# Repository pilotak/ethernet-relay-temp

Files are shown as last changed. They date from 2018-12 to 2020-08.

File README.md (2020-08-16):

# STM32F103C8 (BluePill) based temperature node with relay



## Features
- variable power supply: 5-15V (depends on relay coil)
- 1-wire bus for DS18B20 temperature sensors
- 1x thermistor input
- 1x SPST relay with ARC suppression
- controlled over MQTT

## MQTT topics
- `nameOfBoard/dtemp/*` = dallas temperature *(aterisk is temp address)*
- `nameOfBoard/atemp/*` = thermistor temperature *(aterisk is analog temp index)*
- `nameOfBoard/status` = online status
- `nameOfBoard/err` = dallas error, tells you index of the bad sensor
- `nameOfBoard/count` = number of dallas sensors found
- `nameOfBoard/relay/0` = state of relay
- `nameOfBoard/relay/0/set` = command for relay, can be either `0` or `1`

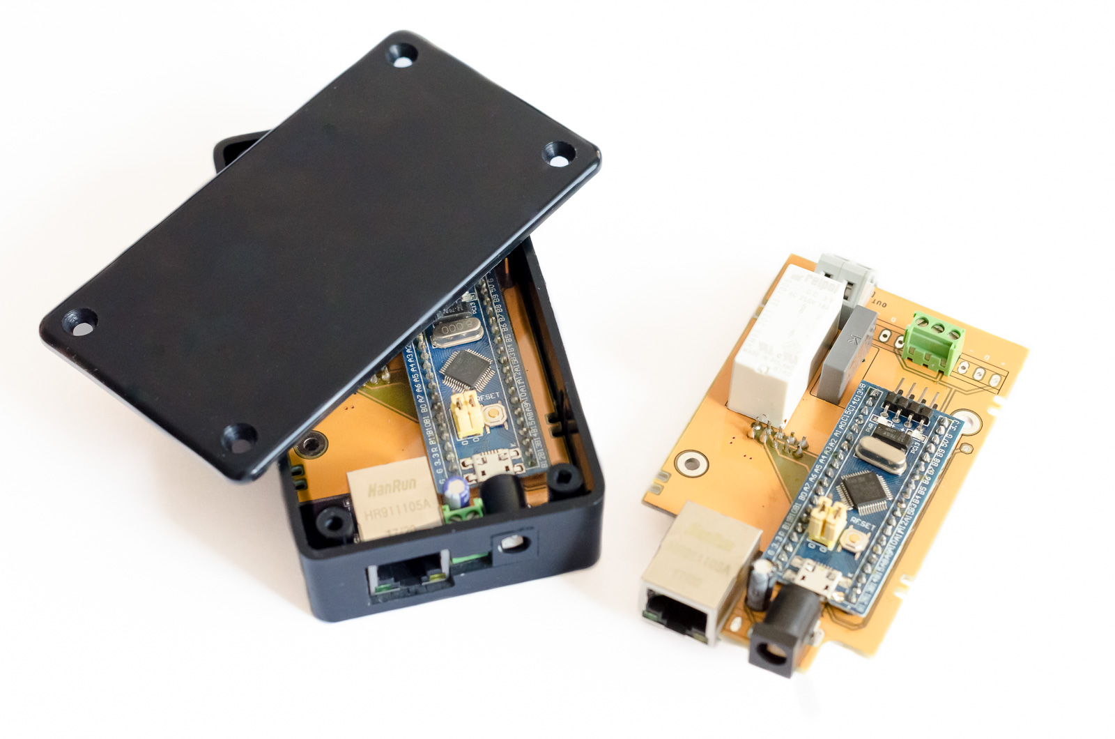
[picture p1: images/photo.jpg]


## BOM
| Qty | Component | Value | Package |
|:---:| --- | ----- | --- |
| 1 | Ceramic capacitor | 10uF | C0805 |
| 1 | Electrolytic capacitor | 100uF | E2-5 |
| 1 | Polypropylene capacitor | R463I24705001K | C150-084X183 |
| 1 | Diode | S1B |DO214AC (SMA) |
| 1 | Shottky diode | SS16 | DO214AC (SMA) |
| 1 | Barrel jack | 2.1mm | |
| 1 | Relay | RM85-2021-35-1005 | |
| 1 | NPN transistor | BC817 | SOT23-BEC |
| 1 | Resistor | 1K | R0805 |
| 1 | Resistor | 4K7 | R0805 |
| 1 | Resistor | 10K | R0805 |
| 1 | Resistor | 160R | R2010 |
| 1 | Ethernet module | ENC28J60 | |
| 1 | LDO regulator | LM1117-3.3 | SOT223 |
| 1 | Processor module | STM32F103C8T6 | |
| 2 | Terminal | Wago 236-740-5,08 | |
| 1 | Terminal | KF350-3.50-2P | |
| 3 | Terminal | KF350-3.50-3P | |
| 1 | Case | KRADEX Z76 | |

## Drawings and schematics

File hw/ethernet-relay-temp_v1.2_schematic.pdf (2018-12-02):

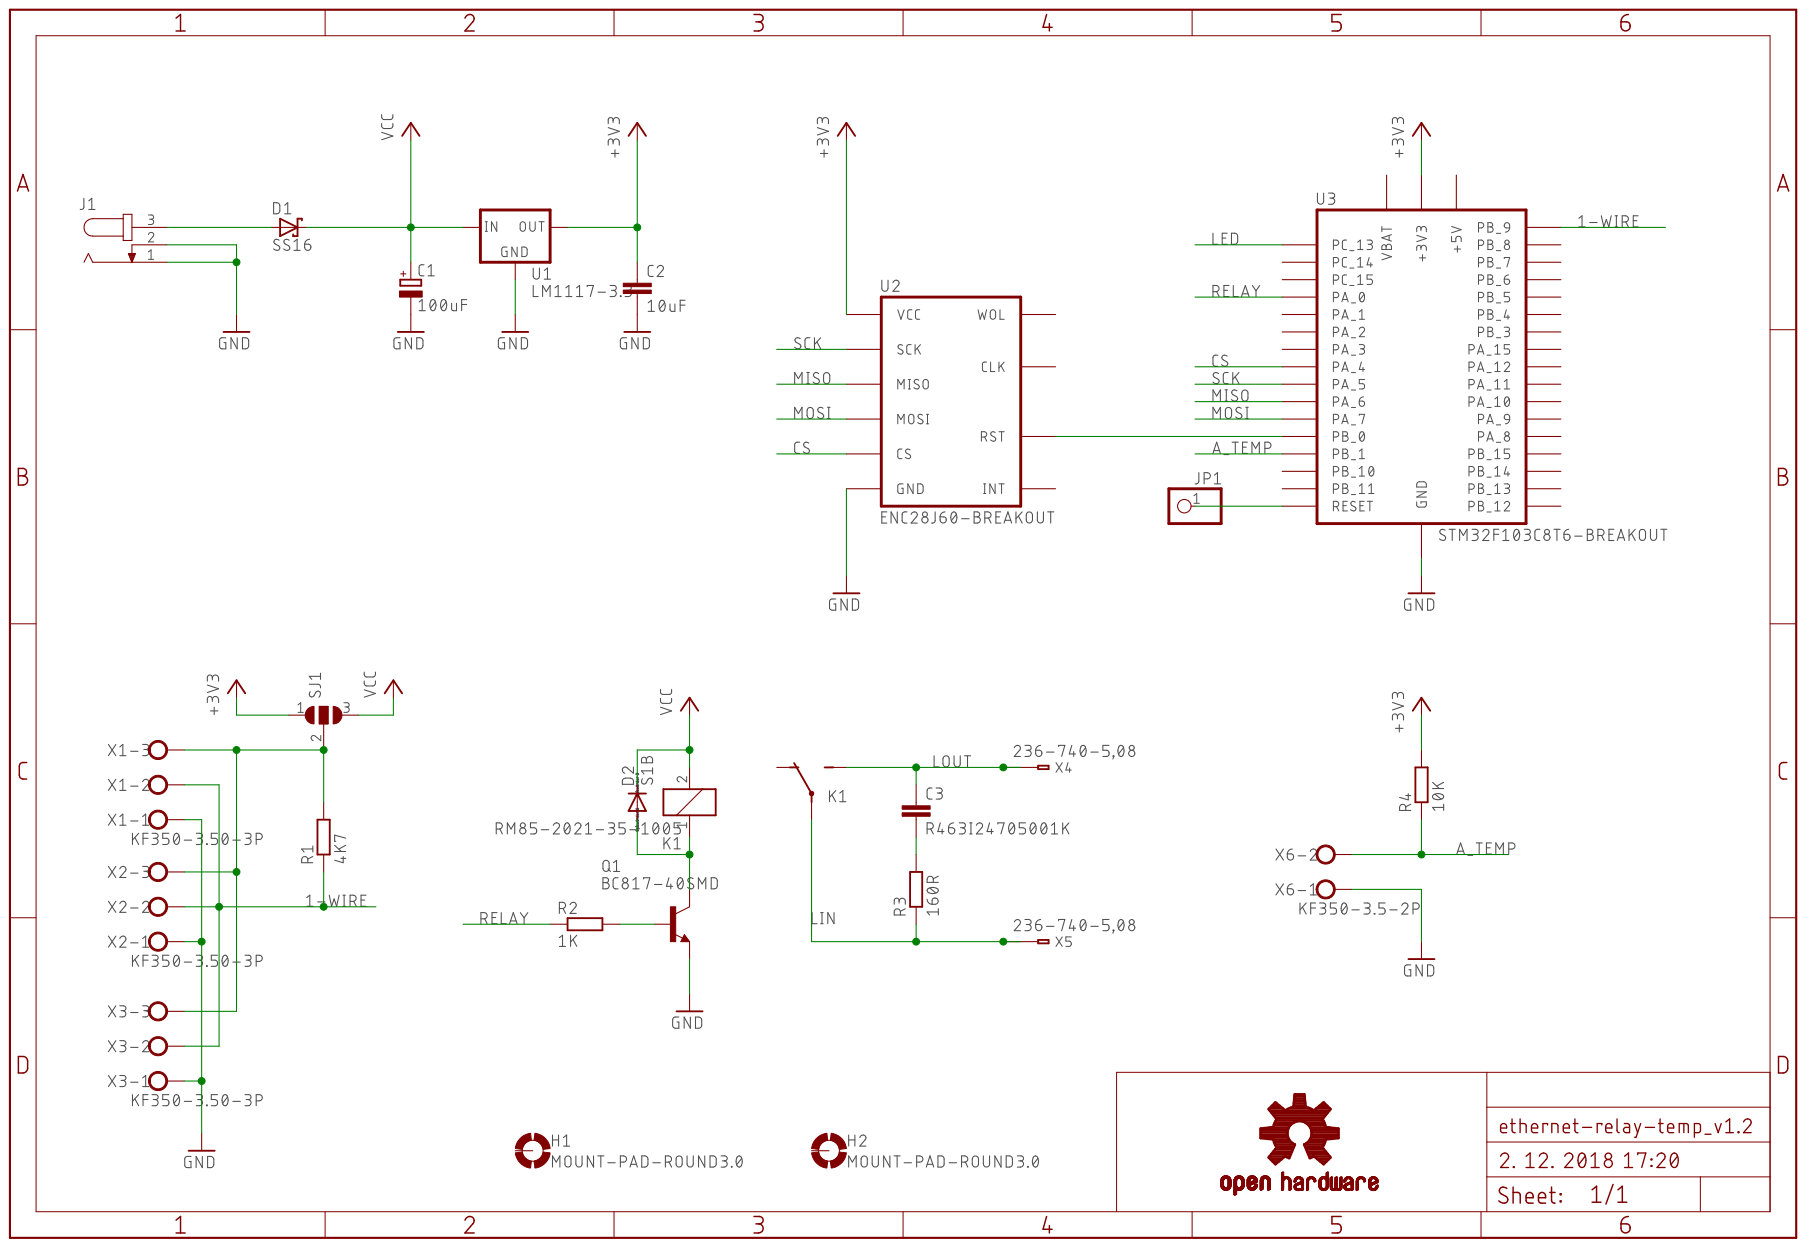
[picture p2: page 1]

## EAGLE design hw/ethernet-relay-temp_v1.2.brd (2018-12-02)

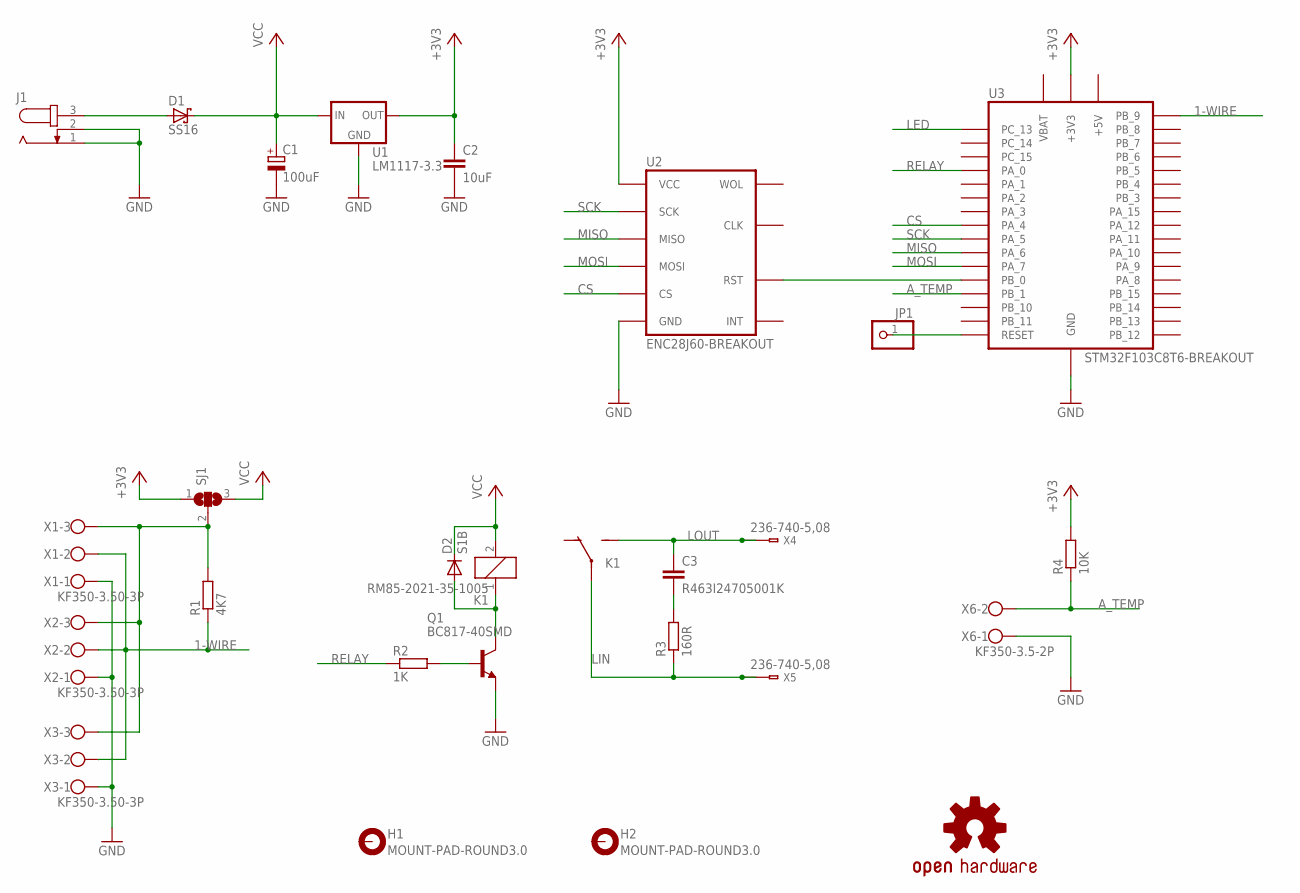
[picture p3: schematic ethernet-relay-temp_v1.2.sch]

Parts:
C1: 100uF; E2-5
C2: 10uF; C0805
C3: R463I24705001K; C150-084X183
D1: SS16; DO214AC
D2: S1B; DO214AC
H1, H2: MOUNT-PAD-ROUND3.0; 3,0-PAD
J1: JACK-PLUG0; SPC4077
JP1: PINHD-1X1; 1X01
K1: RM85-2021-35-1005; RM85
LOGO1: OSHW-LOGOS-COPPER; OSHW-LOGO-S_COPPER
Q1: BC817-40SMD; SOT23-BEC
R1: 4K7; R0805
R2: 1K; R0805
R3: 160R; R2010
R4: 10K; R0805
SJ1: SJ2W; SJ_2
U1: LM1117-3.3; SOT223
U2: ENC28J60-BREAKOUT; ENC28J60
U3: STM32F103C8T6-BREAKOUT; STM32F103C8T6
X1, X2, X3: KF350-3.50-3P
X4, X5: 236-740-5,08; 236-4XX
X6: KF350-3.5-2P; KF350-3.50-2P

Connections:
1-WIRE: R1.1, U3.PB_9, X1.2, X2.2, X3.2
+3V3: C2.1, R4.2, SJ1.1, U1.2 (OUT), U1.4 (OUT), U2.VCC, U3.+3V3, U3.+3V3@1 (+3V3)
+5V: U3.+5V
A_TEMP: R4.1, U3.PB_1, X6.2
CS: U2.CS, U3.PA_4
GND: C1.-, C2.2, J1.1, J1.2, Q1.E, U1.1 (GND), U2.GND, U3.GND, U3.GND@1 (GND), U3.GND@2 (GND), X1.1, X2.1, X3.1, X6.1
LED: U3.PC_13
LIN: K1.11, K1.21, R3.1, X5.1@1 (A1), X5.1@2 (B1)
LOUT: C3.1, K1.14 (NO), K1.24 (NO), X4.1@1 (A1), X4.1@2 (B1)
MISO: U2.SO (MISO), U3.PA_6
MOSI: U2.SI (MOSI), U3.PA_7
unnamed: JP1.1, U3.RESET
unnamed: U2.RST, U3.PB_0
unnamed: C3.2, R3.2
unnamed: D2.A, K1.1, Q1.C
unnamed: Q1.B, R2.2
unnamed: R1.2, SJ1.2, X1.3, X2.3, X3.3
unnamed: D1.A, J1.3
RELAY: R2.1, U3.PA_0
SCK: U2.SCK, U3.PA_5
VBAT: U3.VBAT
VCC: C1.+, D1.C, D2.C, K1.2, SJ1.3, U1.3 (IN)

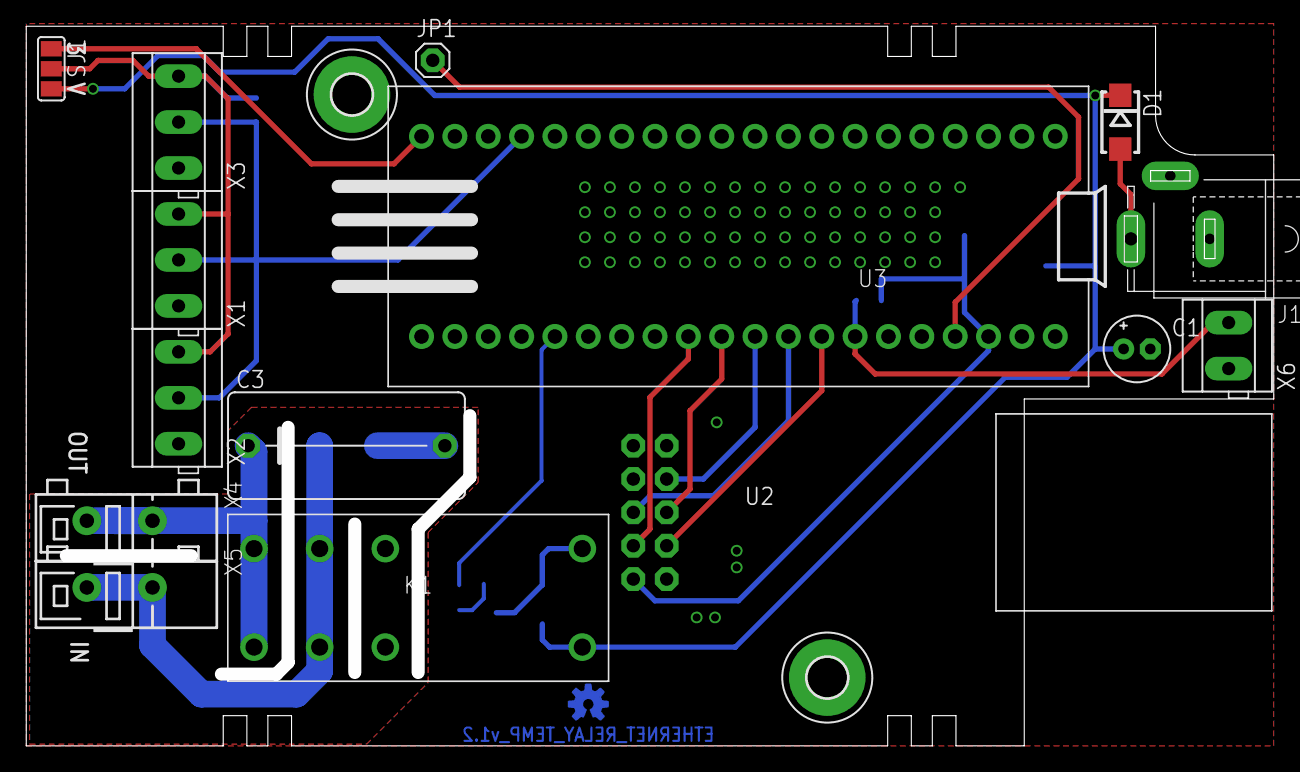
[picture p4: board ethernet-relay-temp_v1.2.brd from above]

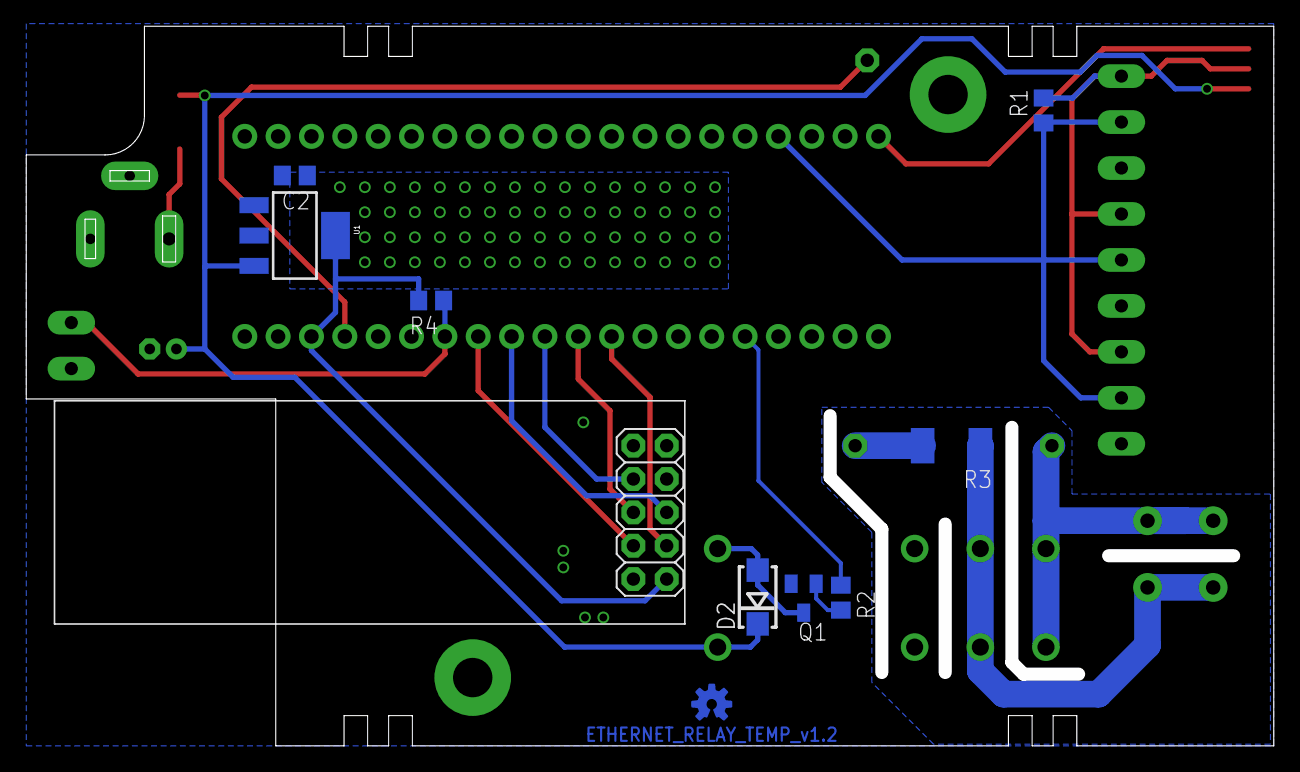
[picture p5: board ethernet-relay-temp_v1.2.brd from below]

Board: 2 copper layers, 95.0 x 54.8 mm, 26 parts (9 on the bottom side), 19 nets.

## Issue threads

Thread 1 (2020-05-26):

Build Issues with Current PIO

GeorgeIoak, 2020-05-26:
I know this project is a bit old but when I tried build it I kept getting errors no matter what I tried. Can you try to compile with an updated install and see if it still compiles for you.

pilotak, 2020-05-27:
Sure, I will look into it

pilotak, 2020-05-28:
I could not get the "old" core compiled. So at "new" core I have fixed the ADC error but at the moment i can't get the watchdog compiled.

I have submitted an issue to PIO https://github.com/platformio/platform-ststm32/issues/396

GeorgeIoak, 2020-05-28:
OK, thanks, I had similar problems but wasn't familiar enough with your code so I'm glad that you found time to check and report an issue to PIO. Hopefully they will reply to your issue in a timely manner.

pilotak, 2020-08-16:
@GeorgeIoak seems to be fixed in stm-core version 8.0.0 you can check in [actions](https://github.com/pilotak/ethernet-relay-temp/actions?query=workflow%3Abuild).
Feel free to reopen if any problem occur.

Closed 2020-08-16.

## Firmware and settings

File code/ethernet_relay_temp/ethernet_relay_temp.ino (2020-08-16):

/*
MIT License
Copyright (c) 2018 Pavel Slama
Permission is hereby granted, free of charge, to any person obtaining a copy
of this software and associated documentation files (the "Software"), to deal
in the Software without restriction, including without limitation the rights
to use, copy, modify, merge, publish, distribute, sublicense, and/or sell
copies of the Software, and to permit persons to whom the Software is
furnished to do so, subject to the following conditions:
The above copyright notice and this permission notice shall be included in all
copies or substantial portions of the Software.
THE SOFTWARE IS PROVIDED "AS IS", WITHOUT WARRANTY OF ANY KIND, EXPRESS OR
IMPLIED, INCLUDING BUT NOT LIMITED TO THE WARRANTIES OF MERCHANTABILITY,
FITNESS FOR A PARTICULAR PURPOSE AND NONINFRINGEMENT. IN NO EVENT SHALL THE
AUTHORS OR COPYRIGHT HOLDERS BE LIABLE FOR ANY CLAIM, DAMAGES OR OTHER
LIABILITY, WHETHER IN AN ACTION OF CONTRACT, TORT OR OTHERWISE, ARISING FROM,
OUT OF OR IN CONNECTION WITH THE SOFTWARE OR THE USE OR OTHER DEALINGS IN THE
SOFTWARE.
*/

#include <climits>
#include "watchdog.h"
#include "settings.example.h"

bool sendData(const char * topic, const char * data, bool retain = false);  // compiler workaround

#include "temp.h"
#include "ethernet.h"

uint32_t previousSendMillis = 0;
uint32_t previousWillMillis = 0;
uint32_t previousReadMillis = 0;
uint32_t previousWdtMillis = 0;

#if defined(ENABLE_DEBUG) && defined(NEW_CORE)
    HardwareSerial debugPort(DEBUG_RX, DEBUG_TX);
#endif

void setup() {
#if defined(ENABLE_DEBUG)
    debugPort.begin(115200);
#endif

    pinMode(INFO_LED, OUTPUT);
    digitalWrite(INFO_LED, HIGH);

    pinMode(RELAY_PIN, OUTPUT);
    digitalWrite(RELAY_PIN, LOW);

#if defined(ENABLE_DEBUG)
    debugPort.println("Starting");
#endif

    ethSetup();

    wdtSetup();

    // setup mqtt client
    mqttClient.setClient(ethClient);
    mqttClient.setServer(MQTT_HOST, MQTT_PORT);
    mqttClient.setCallback(mqttMsg);
    mqttConnect();

    tempSetup();

    previousSendMillis = previousWdtMillis = previousReadMillis = previousWillMillis = millis();
}

void loop() {
    if (millis() - previousWdtMillis >= WDT_INTERVAL) {
        previousWdtMillis = millis();
        wdtFeed();
    }

    if (millis() - previousReadMillis >= SENSORS_READ_INTERVAL) {
        previousReadMillis = millis();
        readTemp();
    }

    if (millis() - previousWillMillis >= MQTT_STATUS_SEND_INTERVAL) {
        previousWillMillis = millis();

        if (!sendData(MQTT_TOPIC_WILL, MQTT_STATE_ON, true)) {
            mqttConnect();
        }
    }

    if (millis() - previousSendMillis >= SENSORS_SEND_INTERVAL) {
        previousSendMillis = millis();
        sendTemp();
    }

    mqttClient.loop();
}

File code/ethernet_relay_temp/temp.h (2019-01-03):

#include <OneWire.h>
#include <DallasTemperature.h>
#include "Hysteresis.h"
#include "MovingAverage.h"

OneWire oneWire(ONE_WIRE_PIN);

DallasTemperature sensors(&oneWire);
DeviceAddress dallasAddresses[MAX_DS18B20];
Hysteresis <int32_t> dHysteresis[MAX_DS18B20];
MovingAverage <int32_t, 32> dAverage[MAX_DS18B20];
Hysteresis <int32_t> aHysteresis[ANALOG_TEMPS];
MovingAverage <int32_t, 32> aAverage[ANALOG_TEMPS];

char address_string[MAX_DS18B20][17];
const char * hex = "0123456789ABCDEF";

uint8_t ds12b20_count = 0;

void tempSetup() {
    for (uint8_t i = 0; i < ANALOG_TEMPS; i++) {
        aHysteresis[i].set(10);
        aHysteresis[i].prev(LONG_MIN);

#if !defined(NEW_CORE)
        pinMode(a_temp_pin[i], INPUT_ANALOG);
#endif
    }

#if defined(NEW_CORE)
    analogReadResolution(12);
#endif

    sensors.begin();
    ds12b20_count = sensors.getDeviceCount();

#if defined(ENABLE_DEBUG)
    debugPort.print("Found ");
    debugPort.print(ds12b20_count, DEC);
    debugPort.println(" devices");
#endif

    ds12b20_count = (ds12b20_count > MAX_DS18B20 ? MAX_DS18B20 : ds12b20_count);  // prevent overflow

    char data[2];
    data[0] = ds12b20_count + '0';
    data[1] = 0;
    sendData(MQTT_TOPIC_COUNT, data, true);

    if (ds12b20_count != 0) {
        for (uint8_t i = 0; i < ds12b20_count; i++) {
            dHysteresis[i].set(10);
            dHysteresis[i].prev(LONG_MIN);

            if (sensors.getAddress(dallasAddresses[i], i)) {
                sensors.setResolution(dallasAddresses[i], TEMPERATURE_PRECISION);

                for (uint8_t j = 0; j < 8; ++j) {
                    address_string[i][(j << 1)] = hex[((uint8_t)dallasAddresses[i][j] >> 4) & 0xF];
                    address_string[i][(j << 1) + 1] = hex[dallasAddresses[i][j] & 0xF];
                }

                address_string[i][16] = 0;  // terminate string

            } else {
                char data[3];
                data[0] = '-';
                data[1] = i + '0';
                data[2] = 0;
                sendData(MQTT_TOPIC_ERROR, data, true);

#if defined(ENABLE_DEBUG)
                debugPort.print("Sending message: Dallas ");
                debugPort.print(i);
                debugPort.println(" error");
#endif
            }

            wdtFeed();
        }
    }
}

void readTemp() {
    float adc;
    float steinhart;
    uint8_t i = 0;
    int32_t temp;

    if (ds12b20_count > 0) {
        sensors.requestTemperatures();
    }

    for (i = 0; i < ds12b20_count; i++) {
        float tempC = sensors.getTempC(dallasAddresses[i]);

#if defined(ENABLE_DEBUG)
        debugPort.print("Dallas temp[");
        debugPort.print(i);
        debugPort.print("]: ");
        debugPort.println(tempC, 3);
#endif

        if (tempC > -127.0) {
            dHysteresis[i].add(dAverage[i].add(static_cast<int32_t>(tempC * 100)));

        } else {
            dHysteresis[i].prev(LONG_MIN);
            dAverage[i].reset();
        }

        wdtFeed();
    }

    for (i = 0; i < ANALOG_TEMPS; i++) {
        adc = analogRead(a_temp_pin[i]);

        if (adc <= 4000) {
            adc = (4095 / adc) - 1;
            adc = A_TEMP_SERIES_RESISTOR / adc;

            steinhart = adc / THERMISTOR_NOMINAL;               // (R/Ro)
            steinhart = log(steinhart);                         // ln(R/Ro)
            steinhart /= BCOEFFICIENT;                          // 1/B * ln(R/Ro)
            steinhart += 1.0 / (TEMPERATURE_NOMINAL + 273.15);  // + (1/To)
            steinhart = 1.0 / steinhart;                        // Invert
            steinhart -= 273.15;                                // convert to C


#if defined(ENABLE_DEBUG)
            debugPort.print("Analog temp[");
            debugPort.print(i);
            debugPort.print("]: ");
            debugPort.println(steinhart, 3);
#endif

            aHysteresis[i].add(aAverage[i].add(static_cast<int32_t>(steinhart * 100.0)));

        } else {
            aHysteresis[i].prev(LONG_MIN);
            aAverage[i].reset();

#if defined(ENABLE_DEBUG)
            debugPort.print("Invalid ADC reading[");
            debugPort.print(i);
            debugPort.println("]");
#endif
        }
    }

#if defined(ENABLE_DEBUG)
    debugPort.println();
#endif
}

void sendTemp() {
    char data[20];
    char topic[50];
    uint8_t i = 0;
    int32_t temp;
    float temp_float;

#if defined(ENABLE_DEBUG)
    debugPort.println("Sending temperatures\n");
#endif

    digitalWrite(INFO_LED, LOW);

    for (i = 0; i < ds12b20_count; i++) {
        temp_float = NAN;
        temp = dHysteresis[i].get();

        if (temp > LONG_MIN) {
            temp_float = static_cast<float>(temp) / 100.0;
        }

        memset(data, 0, sizeof(data));

        if (!isnan(temp_float)) {
            dtostrf(temp_float, 3, 1, data);
        }

        snprintf(topic, sizeof(topic), "%s/%s", MQTT_TOPIC_DALLAS_TEMP, address_string[i]);
        sendData(topic, data, true);

        wdtFeed();
    }

    for (i = 0; i < ANALOG_TEMPS; i++) {
        temp_float = NAN;
        temp = aHysteresis[i].get();

        if (temp > LONG_MIN) {
            temp_float = static_cast<float>(temp) / 100.0;
        }

        memset(data, 0, sizeof(data));

        if (!isnan(temp_float)) {
            dtostrf(temp_float, 3, 1, data);
        }

        snprintf(topic, sizeof(topic), "%s/%u", MQTT_TOPIC_ANALOG_TEMP, i);

        sendData(topic, data, true);

        wdtFeed();
    }

    digitalWrite(INFO_LED, HIGH);
}

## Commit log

2018-12-02 BOM update
    [ci skip]
2018-12-02 pin change
2018-12-02 readme update
    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
    [settings.example.h]
2018-12-08 longer watchdog + temp string fix
    [ethernet_relay_temp.ino, settings.example.h, temp.h]
2018-12-27 wdt + reset update
    [ethernet_relay_temp.ino, temp.h]
2018-12-27 12bit ADC as default
2018-12-27 snprintf to dtostr + fixes
    [ethernet_relay_temp.ino, settings.example.h, temp.h]
2019-01-03 compatibility with new/old STM32 core
2020-05-28 fix adc warning
2020-08-16 folder restructure
    [ethernet-relay-temp_v1.2.brd, ethernet-relay-temp_v1.2.sch]

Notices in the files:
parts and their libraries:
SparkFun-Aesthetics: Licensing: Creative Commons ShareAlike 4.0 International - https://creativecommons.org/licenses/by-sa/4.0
